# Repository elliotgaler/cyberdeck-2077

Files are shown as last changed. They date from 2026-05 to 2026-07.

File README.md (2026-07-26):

# CyberDeck-2077
A (WIP) CyberDeck project themed from the game CyberPunk 2077
CyberDeck -  a small, retro mini-pc running off basic hardware. They're a trend at the moment, which is where i got the idea to make one
The case, clips, hinges, attatchments etc. are all designed to be 3d printed, and attatched together with m2/m3 screws. I made this project because i have an interest in cybersecurity, and wanted to make a small, portable device that i could use to practice on. Even though it isn't hugely functional for that purpose right now (using only a relatively slow pi5), it is designed so that I have plenty of space to adapt it in the future if I want to. I love the game CyberPunk 2077, the associated tv show, and the cyberpunk style as a whole, and thought it an ideal aesthetic inspiration for the project.   
The cyberdeck features:
- Rasberry Pi 5 as the mainboard
- a 7 inch 1024x600 monitor
- a Rii x1 mini keyboard
- other components (rear ethernet port, usb-c port, cooling fan)

What i intend to use the deck for:
i'm super into cybersecurity rn and im hoping to go into work in that industry, so i'm going to insall some sort of linux distro (arch/kali) designed for cybersecurity and use it to practice skills related to cybersec. i also intend to do some other projects in fallout to compliment it. I might expand it in the future to include an internal battery, but i'm leaving it as a wall-power only for simplicity for now.

Future changes/plans:
- update USB ports on LowerCaseCover to fit the actual hub
- Add an internal battery
- integrate my other projetct (DiyRubberDucky), adding storage/attachment points
- 

FILES:  
construction files - the fusion CAD files, for the assembled and blown-up design + step files for ease of use
3mf files - the files ready for printing on a 3D printer  
documentation - word docu that i made to help me with the process + images of the process + bill of materials + fallout zine + wiring diagram

NOTE - as this is a WIP, files may not be fully functional as of 04/05/26 (dd/mm/yy) - hopefully once i physically build the cyberdeck, i can correct any small issues e.g. USB ports being misplaced due to a lack of dimensions on the product page for the USB hub

Copy of CyberDeck zine pdf







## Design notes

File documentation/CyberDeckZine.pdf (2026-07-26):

2077

## A Cyberpunk 2077-themed Cyberdeck/Mini PC

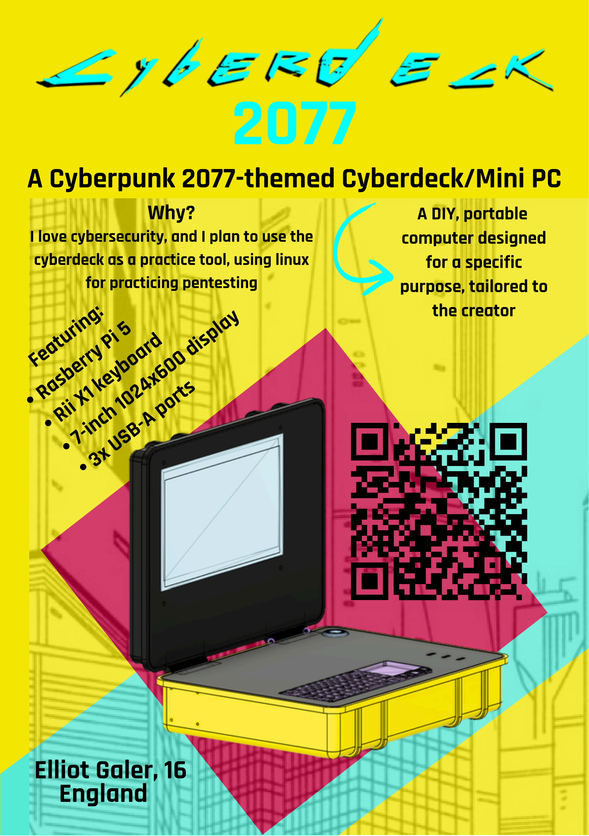
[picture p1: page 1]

## Elliot Galer, 16 England

### Featuring: Rasberry Pi 5 Rii X1 keyboard 7-inch 1024x600 display 3x USB-A ports

A DIY, portable
computer designed
for a specific
purpose, tailored to
the creator

### Why?

I love cybersecurity, and I plan to use the cyberdeck as a practice tool, using linux for practicing pentesting

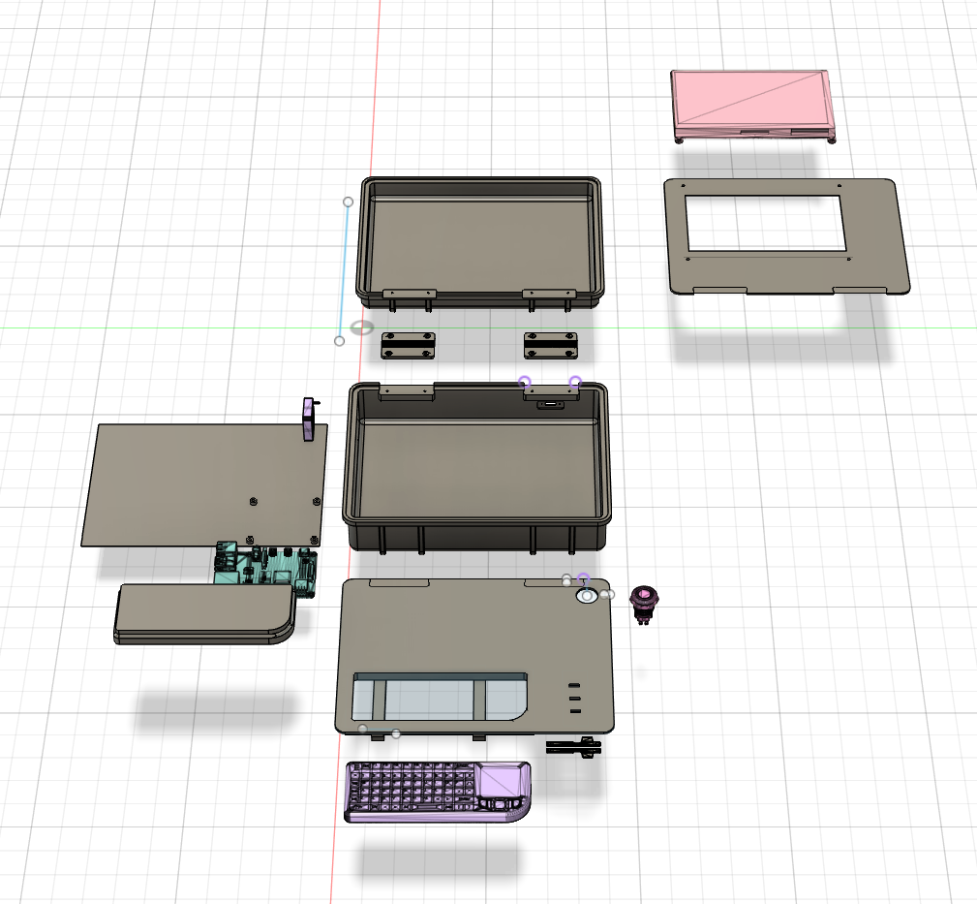
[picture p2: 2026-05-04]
documentation/images/Screenshot 2026-05-04 172059.png

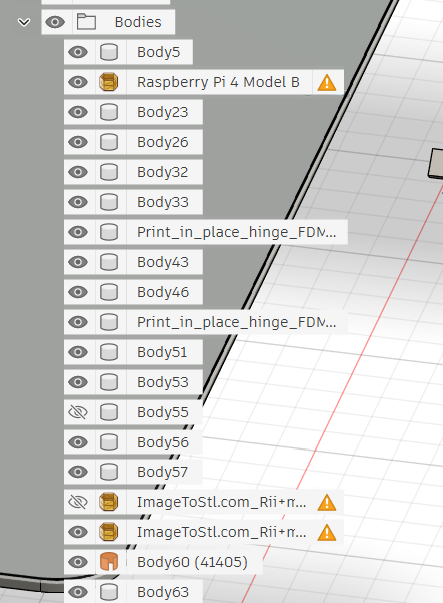
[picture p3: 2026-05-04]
documentation/images/Screenshot 2026-04-29 211012.png

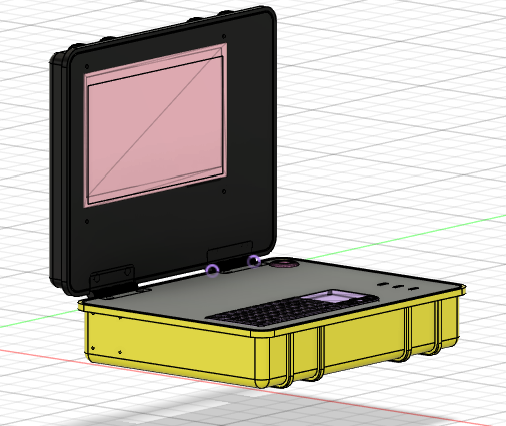
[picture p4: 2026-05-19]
documentation/images/Screenshot 2026-05-05 175419.png

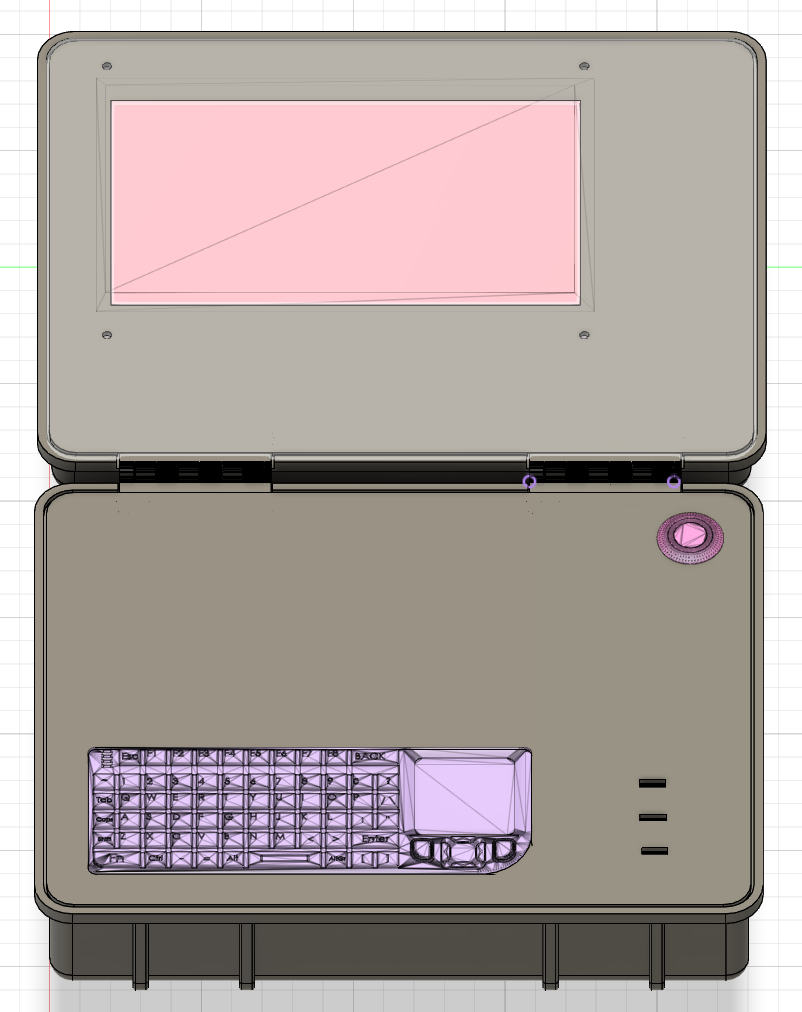
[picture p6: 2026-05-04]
documentation/images/Screenshot 2026-05-04 172925.png

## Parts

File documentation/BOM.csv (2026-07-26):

Bill of Materials
 | NAME | DESC | LINK | UNIT PRICE | UNIT AMOUNT | RUNNING TOTAL
 | Rasberry Pi 5 | The mainboard of the project | https://shorturl.at/4AiOK | £43.20 | 1 | £43.20
 | 7 Inch Screen | The screen for video output | https://shorturl.at/TB3XK | £20.19 | 1 | £63.39
 | Rii X1 keyboard | The keyboard/pointer for input | https://shorturl.at/DzRTy | £12.09 | 1 | £75.48
 | Rasberry Pi heatsink | Heatsink for the pi board | https://shorturl.at/3djcr | £1.89 | 1 | £77.37
 | Dupont cable | Cables for using pi pins | https://shorturl.at/Kwtkn | £1.28 | 1 | £78.65
 | Push button | Start button for pi board | https://rb.gy/n7qr61 | £2.06 | 1 | £80.71
 | Usb C splitter | Splitter to power board+screen | https://shorturl.at/PziXz | £2.38 | 1 | £83.09
 | USB hub | Hub to take ports to outside of case | https://shorturl.at/EItCf | £1.00 | 1 | £84.09
 | M2 screws | Screws for attaching parts | Purchase at hardware store (https://shorturl.at/QgxTS) | £0.10 | 25 | £86.59
 | M3 screws | Screws for attaching parts | Purchase at hardware store (https://shorturl.at/QgxTS) | £0.10 | 4 | £86.99
 | M2 inserts | For attaching screws to plastic | Purchase at hardware store (https://shorturl.at/QgxTS) | £0.10 | 25 | £89.49
 | M3 inserts | For attaching screws to plastic | Purchase at hardware store (https://shorturl.at/QgxTS) | £0.10 | 4 | £89.89
 | Ethernet extender | For external ethernet port | https://shorturl.at/F6xKs | £1.60 | 1 | £91.49
 | 3007 fan | 30mm fan for cooling pi | https://shorturl.at/X9jGS | £1.92 | 1 | £93.41
 | Wires | Wires for connecting components | Purchase at hardware store (https://shorturl.at/BUKeM) | £2.00 | 1 | £95.41
 | PETG fillament | High-strength fillament for printing case components | https://shorturl.at/1YEJ3 | £13.99 | 1 | £109.40
 | SD card extender | Cable for taking sd card from outside of case | https://shorturl.at/Pyktu | £1.99 | 1 | £111.39
 | USB-C extender | Cable for taking USB-C from the back of case | https://shorturl.at/ff3qk | £1.26 | 1 | £112.65
 | Micro-HDMI to HDMI | Cable for taking video from pi5 to display | https://shorturl.at/XtR4Q | £1.99 | 1 | £114.64
 | Keyboard power cable | Cable to power/charge keyboard | https://shorturl.at/65F7K | £2.12 | 1 | £116.76

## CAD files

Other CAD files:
Construction files/CyberDeckAssembled.step
3mf files/LowerHalf.3mf
3mf files/CableClip.3mf
Construction files/CyberDeckExpanded.step
3mf files/HingeUpper.3mf
3mf files/PiPlate.3mf
3mf files/UpperPlate.3mf
3mf files/UpperHalf.3mf
3mf files/UsbHubBar.3mf
3mf files/KeyboardBar.3mf
3mf files/LowerPlate.3mf
3mf files/HingeLower.3mf
Construction files/CyberDeckAssembled.f3d
Construction files/CyberDeckExpanded.f3d

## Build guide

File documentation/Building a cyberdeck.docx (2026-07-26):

Building a cyberdeck – documentation

Basic steps to building:

1. Research and idea building– researching what other people have done with their cyberdecks aesthetically – sizes, shapes, what containers to use/design etc. Then, research on electric components – what mainboard to use, keyboard, screen, battery/power connector etc. for the basics. Further components – USB hubs, Wi-Fi connectivity, buttons etc.
2. Initial CAD – designing the case, the slots for the components to sit – testing using placeholders etc.
3. Production and installation – Produce the final versions of the components, order the hardware, solder it all together and install into the case (maybe program first, depending on difficulty), finalise design.
4. Software – installing operating systems, connecting components together, downloading software etc.

STEP 1: RESEARCH:

Inspiration photos

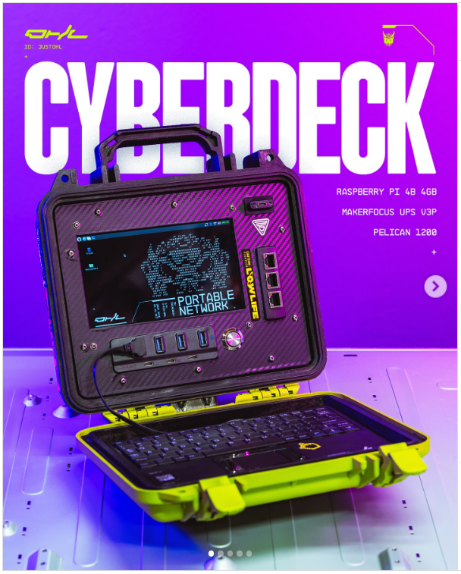
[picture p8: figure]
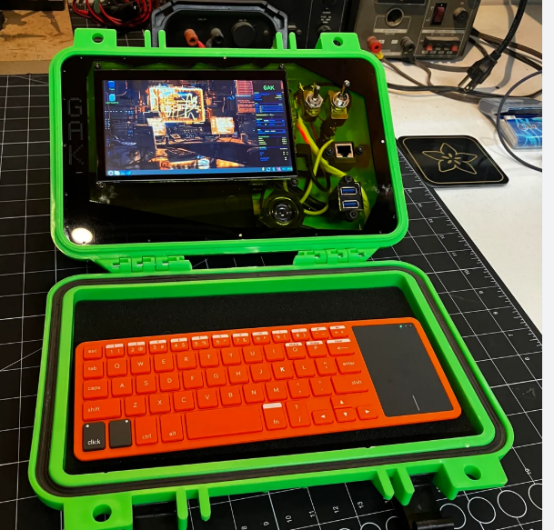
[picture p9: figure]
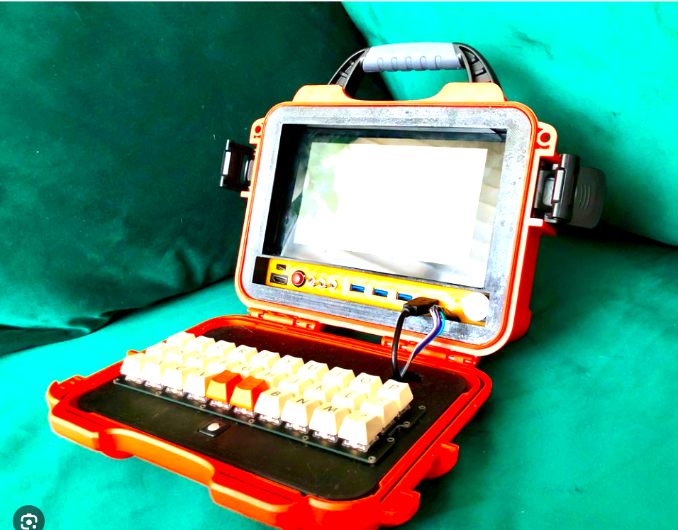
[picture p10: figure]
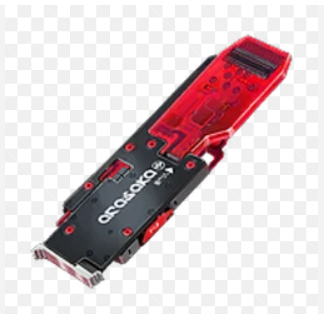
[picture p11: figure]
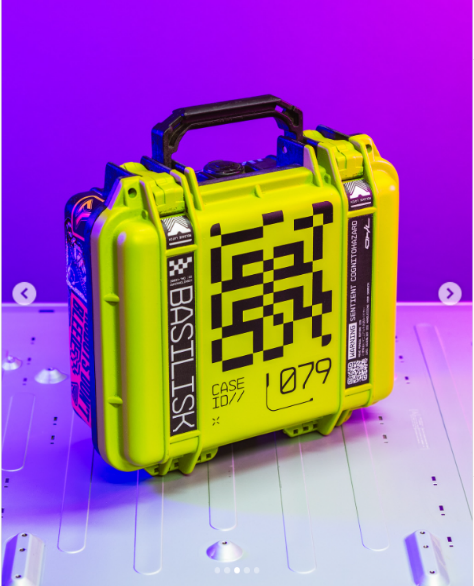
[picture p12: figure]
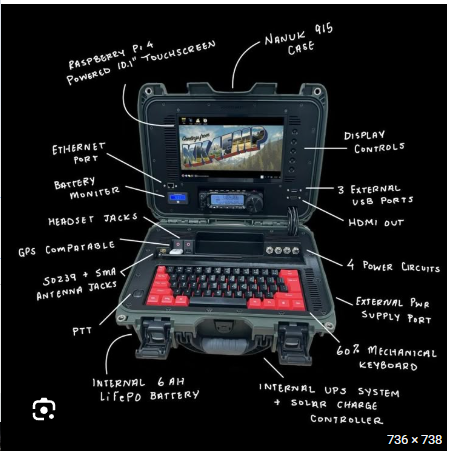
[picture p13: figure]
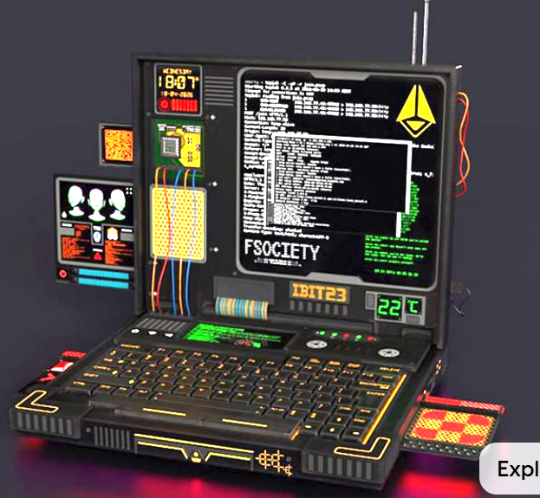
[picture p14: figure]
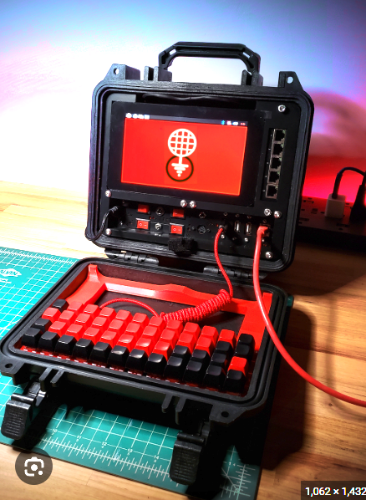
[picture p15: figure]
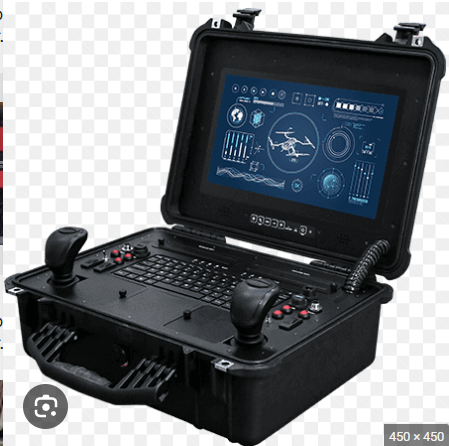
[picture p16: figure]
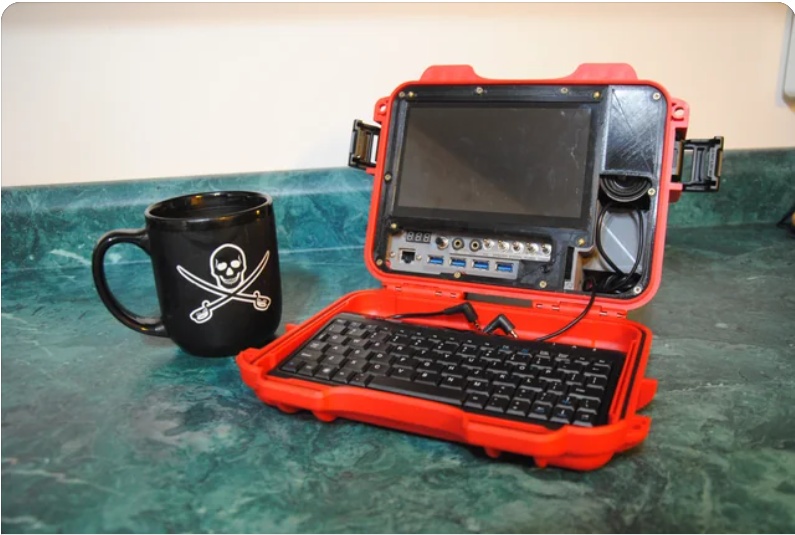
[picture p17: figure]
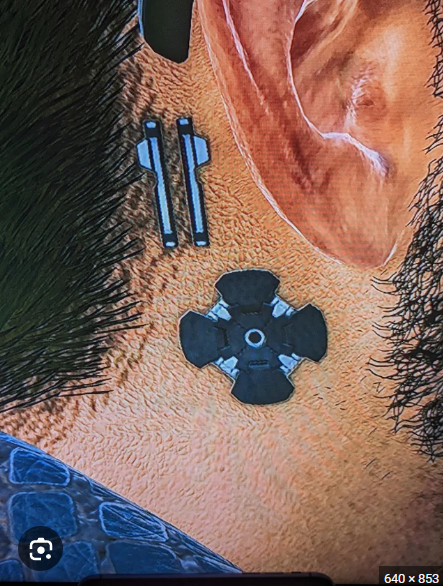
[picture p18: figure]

Idea building

Essentially – a cyberpunk themed cyberdeck. It should have basic computer functionality using some sort of small computer board – probably a raspberry Pi. It’ll have a keyboard and screen integrated, but a wireless mouse separately. I’d like it to have some sort of USB ports, probably using a usb hub that has the ports sat on the bottom half of the deck, and I’d quite like to have in in the style of a Neural port from cyberpunk (decorative only) as well as an audio port in the style of the personal link port (from the game). It should have WiFi connectivity, but that’s not an initial priority for it. Maybe I’ll also add an ethernet port, mostly for aesthetic purposes. It will need a power port of some sort somewhere, but I’m not sure if I want it to run off a battery or a wire. Maybe both, but I’m not sure how to do both now. A small screen for a battery monitor would be cool as well. It would also be cool to use the cyberdeck USB ports as an upgrade port as well, so that I could add more features in the future easily. For WiFi, it would need external antenna, so those would have to fit in somewhere. The whole cyberdeck should be able to fold shut, for transportation.

Electronics/components research

List of electronic components I might need:

1. Computer – the main computer for the cyberdeck. I’m going to use a raspberry pi, either the 3 or 4. The 4 seems better value – I think the 1gb ram is best, as the project is on a budget, and I can always upgrade the board later. Maybe use pi5 if budget allows. Approx. £33
2. Keyboard – a keyboard to integrate into the cyberdeck. Needs to be small, and able to fit nicely into the case. Also needs to be able to be strongly fixed in place somehow. Some sort of cheap amazon keyboard. Approx. £6
3. Main Screen – a screen to show the display of the computer. Ideally colour-enabled, but resolution and refresh rate can be low. Size needs to be 10-15cm wide and 7-12cm tall approx. https://shorturl.at/wK7ne from ali - good option. Approx. £36
4. Secondary screen – next to the main one
5. Battery/Power connector – for power for the components. Battery makes it portable, but power cable is probably cheaper/easier. Also battery requires charging board, and idk about those. I’m going to use a power cable -cheaper, easier. Can add battery later. Can use standard usb-c cable as power, so no charge there, but need usbc-f to usbc-m to take power from outside of case so approx. £3
6. Ethernet-to-ethernet cable – to extend the ethernet port from the pi board. I plan to initially use ethernet for internet connection as I think it’s easier (unless the computer has wifi built in) approx. £2
7. Audio jack extender – for the audio port on the deck. Approx £1
8. USB hub- for getting more USB ports. Approx. £3
9. Small fan for cooling computer board. Approx. £

List of electronic components I already have:

1. Wires – wires to connect the components (apart from the high-gauge wires for power)
2. Screws/bolts – for connecting things to the case
3. Hard drive for storage for the pc

List of non-electronic components I need:

1. 3D printing filament – something strong, and rigid, and that won’t decay over time. Ideally PETG or PCTG, as they are the strongest filaments I can safely print on my A1. PCTG is quite a bit more expensive, but also a bit stronger than PETG. I intend to use white filament so that anything I print can be easily painted over. Potentially, I’ll use white PCTG for only the outside case and then cheaper PETG for anything inside that is less structurally important. This would save costs. Already have PETG, assume ½ kilo of PCTG, so approx. £11
2. Metal rods – for the hinges of the case. use, approx. 4 Approx. £3
3. Heat-set inserts – for screwing things into the case (maybe not needed). approx. £2
4. Small heatsink for pi board. Approx. £4

Total approx. cost (very rough) = £101, $140

$140 dollars is 28hrs of work with grants from fallout, so some will probably be self-funded? Things to complete that are time-heavy is CAD, Installation, Software, and decoration etc.

STEP 2 – 3D modelling

CASE:

Case features:

Max 256mm square (3d print limits)

Ideally rectangular (1:1.3 size ratio)

Handle

Hinges

Should look like a carry case when closed

Dimensions:

I think about 23cm by 17.5cm is ideal, as it leaves plenty of space on the printer. Depth should be enough to store all components, but not too big. Start with 4cm deep

Internal dimensions (mm):

169.2 x 224.2 x 40 – main body

179 x 234 x 2 – lip at top

Useable base dimensions (need to print base parts separately as can’t print upside down):

160.3mm x 215.3mm

Will glue into case after printing

MODELLING SPACES FOR COMPONENTS

I need to model in spaces for components to fit – for parts I know what they will be, I’ll do it exactly, and for others, I’ll do it for a generic part that should be approx. the right size

Parts I know:

1. Raspberry Pi 4
2. 7 inch raspberry pi screen (need top half)

Generic parts:

1. Keyboard (temp)
2. Power cable connectors/ports (will vary largely in size, so may leave generic until purchases are made)
3. 30mm fan
4. USB hub

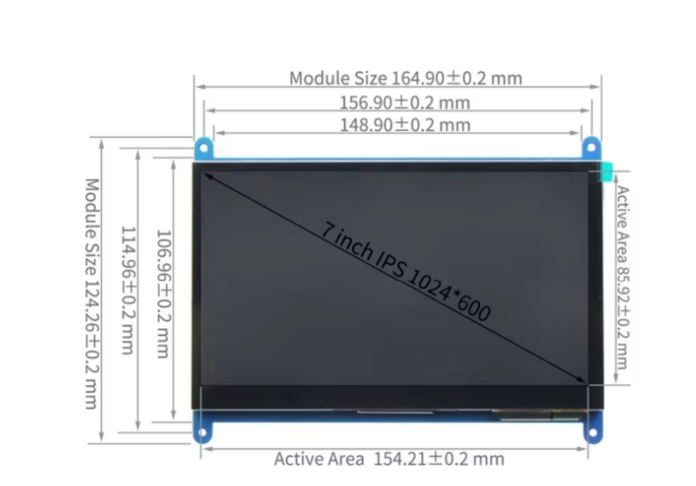
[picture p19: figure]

List of things that need changing after purchasing components:

- Screen hole
- Usb dock holesx

Fixing the files for final production

What needs fixing:

1. Add a hole for the ethernet cable connector on the back(DONE)
2. Move USB ports and make an accurate holder for the hub(DONE)
3. Make a way for cables to go from lower case to upper case (potentially combine with 1?) (DONE) (cables will be wrapped in electrical tape and a stopper will limit the angle of opening)
4. Build stopper for the cables to limit case angle (DONE)
5. Check fit for screen(DONE)
6. Check hole sizes for all screws+inserts

Test prints before final print:

1. Usb hub(DONE)
2. Keyboard(DONE)
3. Rear ethernet and usb-c holes (DONE-PERFECT)
4. Display(DONE)(maybye redo?)
5. Cable clips(DONE-PERFECT)

Screws/screw types needed:

8x m4 for hinges (+inserts)

16x m3 for case covers(+inserts)

8x m3 for usbhub and keyboard(+inserts)

4x (unknown, m2.5-3ish) for display

4x m2.5 for pi 5(screw straight into plastic?)

4x m2/2.5 for fan(need 4x small nut to hold it)

4x (same as display) for ethernet and usbc ports

Further features to decide on adding:

- Handle
- Locking clasps

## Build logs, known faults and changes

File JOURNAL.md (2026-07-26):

# CyberPunk Cyber-deck — Journal Export

- Exported at: 2026-07-26T12:44:38Z
- Project ID: 2610
- Entries: 27

## Entry 1
- ID: 3891
- Author: elliotgaler
- Created At: 2026-04-25T16:24:21Z

### Content

This is the journal for my project, a Cyberpunk 2077-themed cyberdeck

25/04/26
I started research today, starting with photo inspiration for the project and laying out steps that I need to take to complete the project.

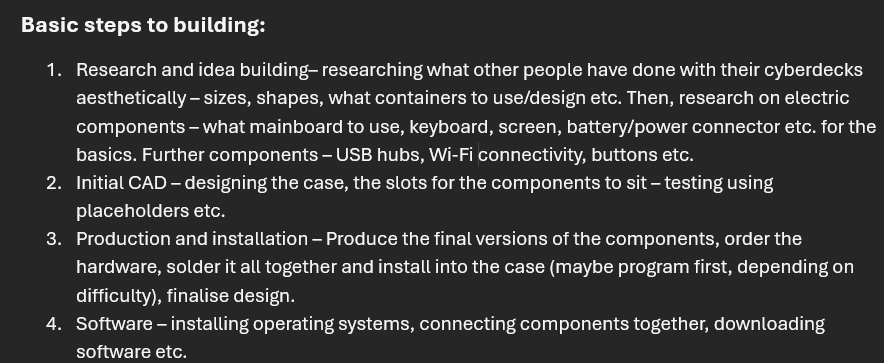
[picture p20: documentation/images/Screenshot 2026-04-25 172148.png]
Screenshot 2026-04-25 172148.png


I wrote out the basic idea of what I wanted from the finished product, and then compiled a list of the components that I would need for the project and their approximate prices, so that I could estimate the cost of the project.

### Recording Links

- https://lookout.hackclub.com/api/media/4405ce72-c4b7-4363-a341-66e24b83303a/video.mp4

## Entry 2
- ID: 4051
- Author: elliotgaler
- Created At: 2026-04-26T14:29:58Z

### Content

26/4/26
Started off with some updated research into mainboards and keyboards, and found better components than I had previously - I decided I didn't want to use a small keyboard like the KeebDeck that I had looked at before, so I decided to use a cheap 40%/mini Bluetooth keyboard

Moved into the beginnings of the CAD for the case of the cyberdeck, starting with the bottom of the case. Fairly simple to design, just took time to polish it off, and I'm sure it'll change again. At this point, it is just the bottom section of the case hollowed out, with decorative details on the outside but no hinges, clasps, or slots for hardware to be installed. 
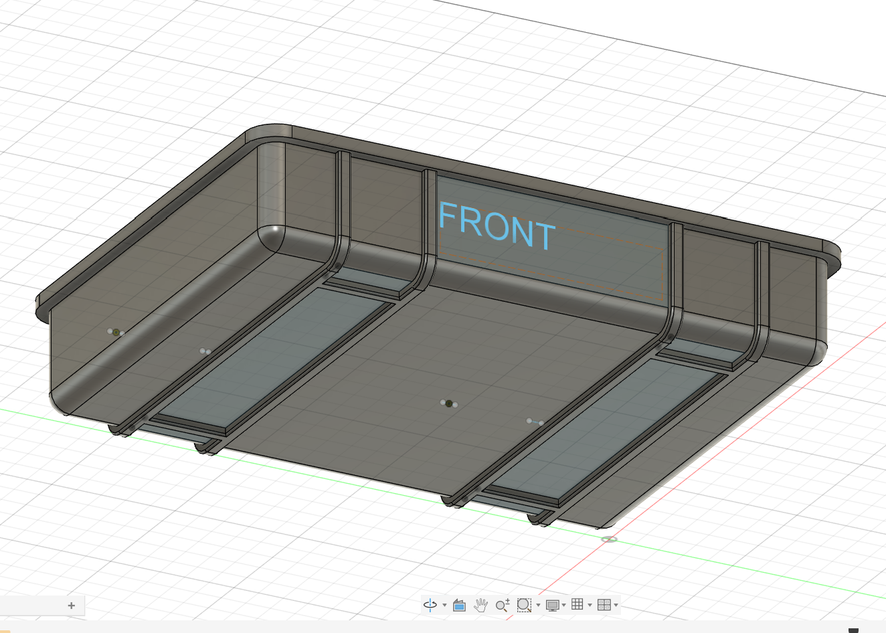
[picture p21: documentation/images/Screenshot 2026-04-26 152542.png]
Screenshot 2026-04-26 152542.png

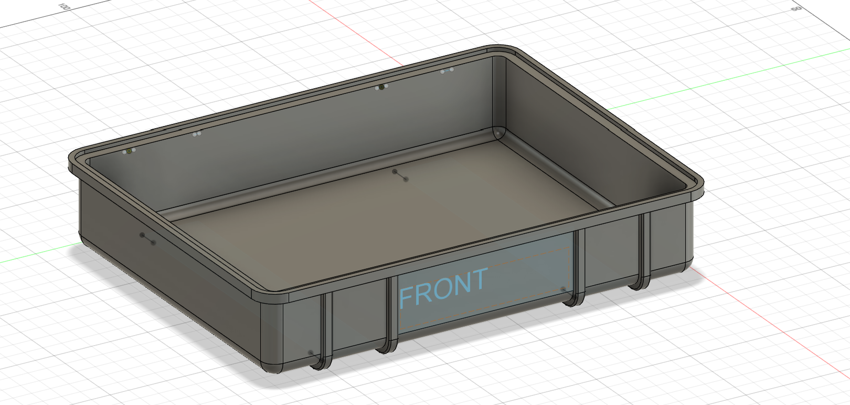
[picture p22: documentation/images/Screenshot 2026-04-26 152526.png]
Screenshot 2026-04-26 152526.png

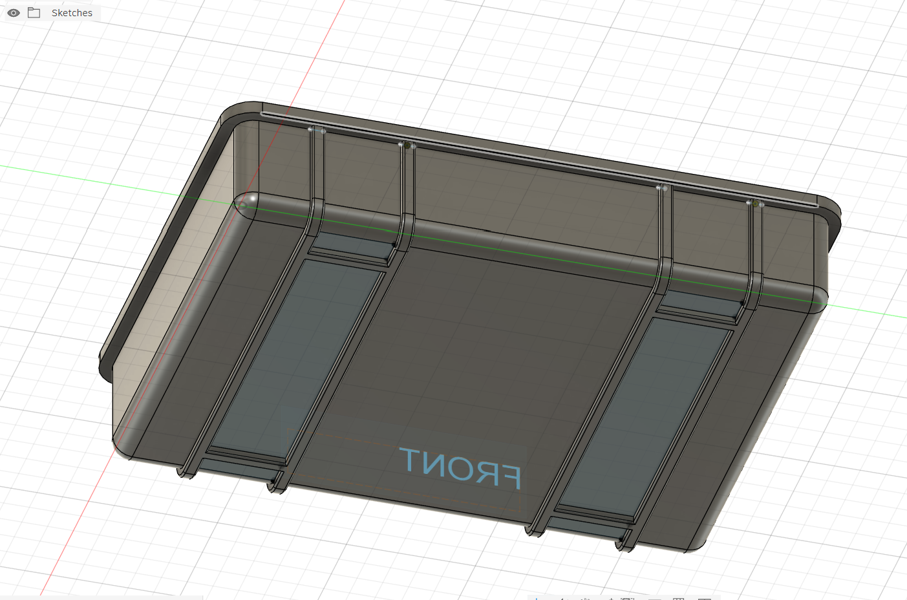
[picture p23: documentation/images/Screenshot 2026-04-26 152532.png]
Screenshot 2026-04-26 152532.png


### Recording Links

- https://lookout.hackclub.com/api/media/2600a046-b6fb-48de-bc44-524a75f680ac/video.mp4

## Entry 3
- ID: 4106
- Author: elliotgaler
- Created At: 2026-04-26T19:27:00Z

### Content

Did more CAD for the case, started building slots for specific electronics (Pi 4) and designing the top cover for the bottom part of the case
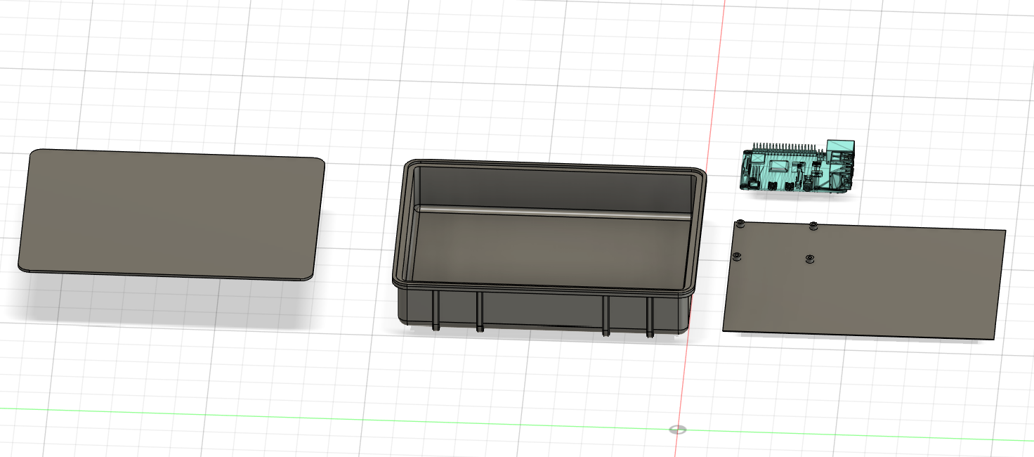
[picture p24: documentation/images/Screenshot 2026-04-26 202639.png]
Screenshot 2026-04-26 202639.png


### Recording Links

- https://lookout.hackclub.com/api/media/1ac716ec-1ffa-4c89-8069-7bb2de2314b7/video.mp4

## Entry 4
- ID: 4267
- Author: elliotgaler
- Created At: 2026-04-27T20:38:56Z

### Content

27/4/26
Further design on the bottom part of the case, and messing around with ideal screw sizes and the hinges. Did a test print for some Print-in-place hinges which went well :). Lots of errors made, screw sizes are really confusing. 
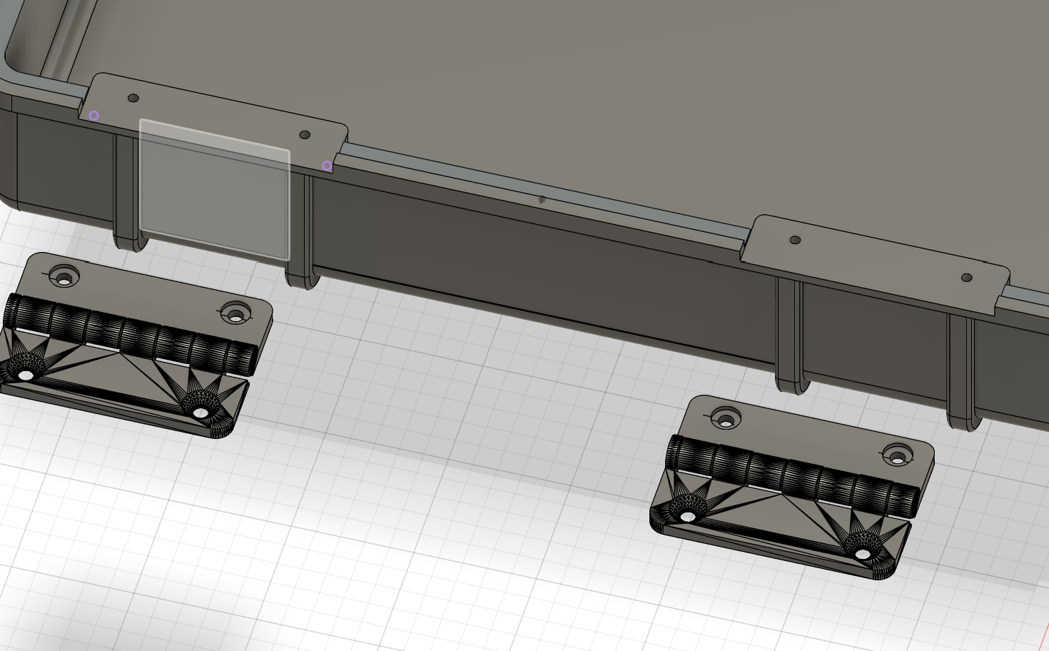
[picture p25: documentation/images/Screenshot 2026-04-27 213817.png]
Screenshot 2026-04-27 213817.png



### Recording Links

- https://lookout.hackclub.com/api/media/1ab56955-1144-40eb-9cbb-87490f9fc08d/video.mp4

## Entry 5
- ID: 4382
- Author: elliotgaler
- Created At: 2026-04-28T18:29:13Z

### Content

28/4/26
short cad session starting the design of the top cover for the bottom case, and rounding corners
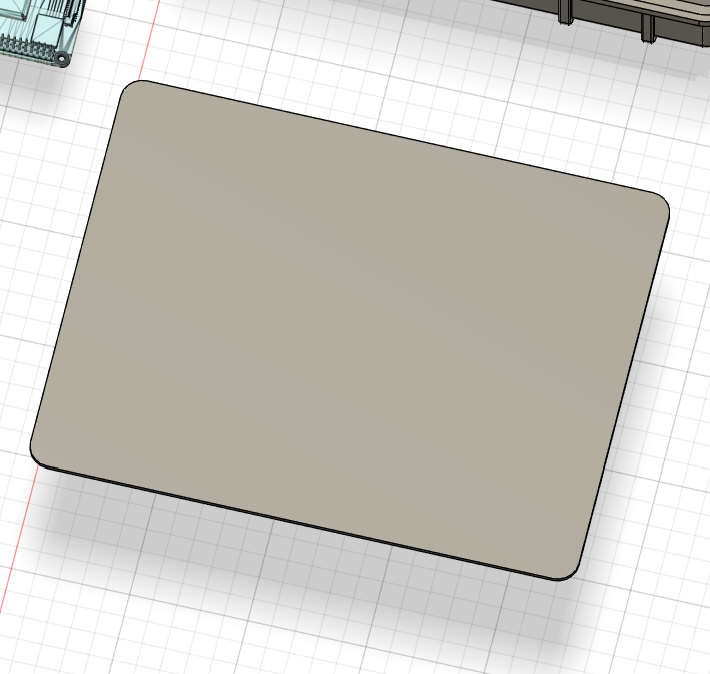
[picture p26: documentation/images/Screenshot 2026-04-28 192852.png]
Screenshot 2026-04-28 192852.png


### Recording Links

- https://lookout.hackclub.com/api/media/fa9d5c09-42ec-4346-9267-840f83a7d7f0/video.mp4

## Entry 6
- ID: 4404
- Author: elliotgaler
- Created At: 2026-04-28T21:13:43Z

### Content

more work on the top cover of the bottom part of the case, and struggling to import a mesh (damm stl files).
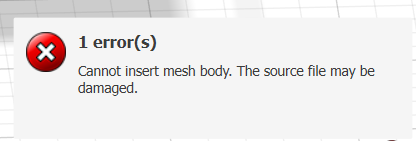
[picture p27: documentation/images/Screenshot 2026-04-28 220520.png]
Screenshot 2026-04-28 220520.png


### Recording Links

- https://lookout.hackclub.com/api/media/162b790a-8967-47d8-9a10-9dfb21c4fbe0/video.mp4

## Entry 7
- ID: 4537
- Author: elliotgaler
- Created At: 2026-04-29T20:39:21Z

### Content

Trying to use a model of my chosen keyboard component to model a spot for it in the case but obviously fusion doesn't like me so had to start modelling the component entirely by hand
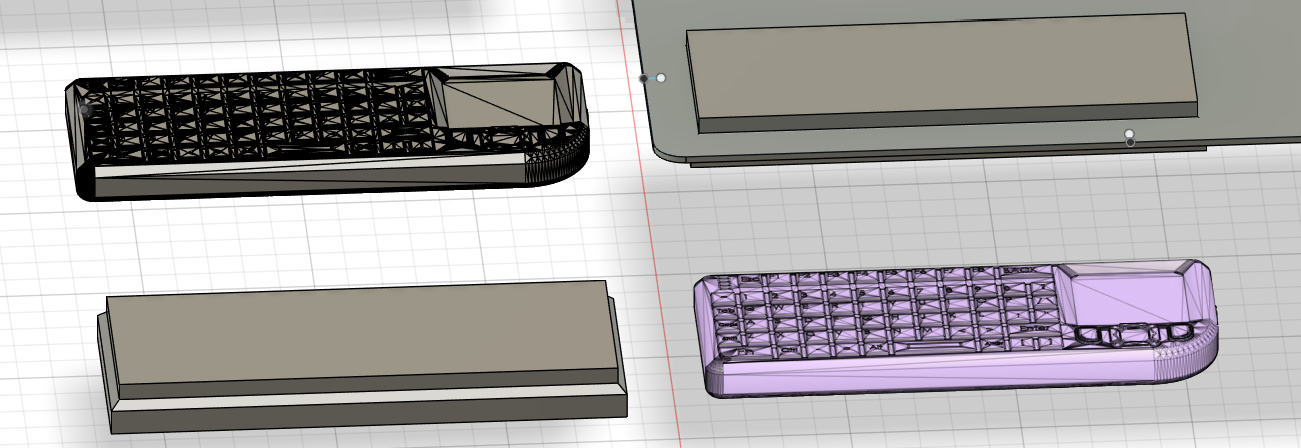
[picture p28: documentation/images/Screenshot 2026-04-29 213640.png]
Screenshot 2026-04-29 213640.png


### Recording Links

- https://lookout.hackclub.com/api/media/3b6cbe93-75dd-45b8-ae53-1bca4c2292b3/video.mp4

## Entry 8
- ID: 4669
- Author: elliotgaler
- Created At: 2026-04-30T20:41:50Z

### Content

More CAD for the keyboard component, went mostly well and defo getting closer to finishing the lower half of the case :)
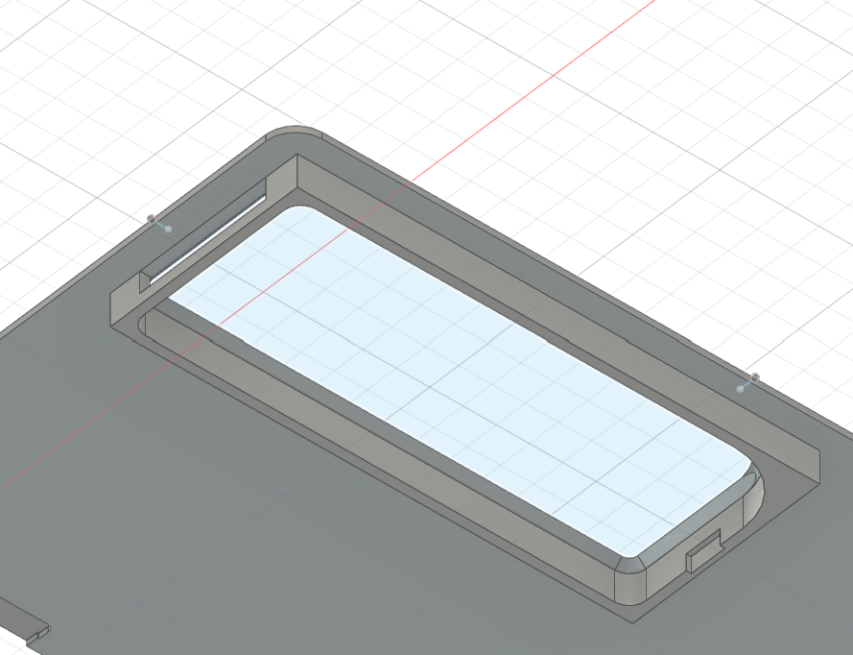
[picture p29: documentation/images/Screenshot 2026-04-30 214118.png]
Screenshot 2026-04-30 214118.png

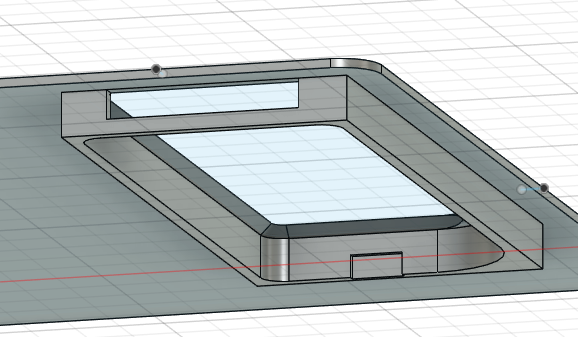
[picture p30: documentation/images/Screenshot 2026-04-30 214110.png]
Screenshot 2026-04-30 214110.png


### Recording Links

- https://lookout.hackclub.com/api/media/5db4787d-8cb6-46ae-9753-4c0dfce4b329/video.mp4

## Entry 9
- ID: 5323
- Author: elliotgaler
- Created At: 2026-05-03T19:05:42Z

### Content

More cad for the bottom case cover, inserting fasteners for the keyboard and holes for the usb ports and power button (both temp as don't know actual dimensions of components), and designed cover for top half of case including mounting points for the screen. Also more component research (power buttons, usb-c splitters etc)
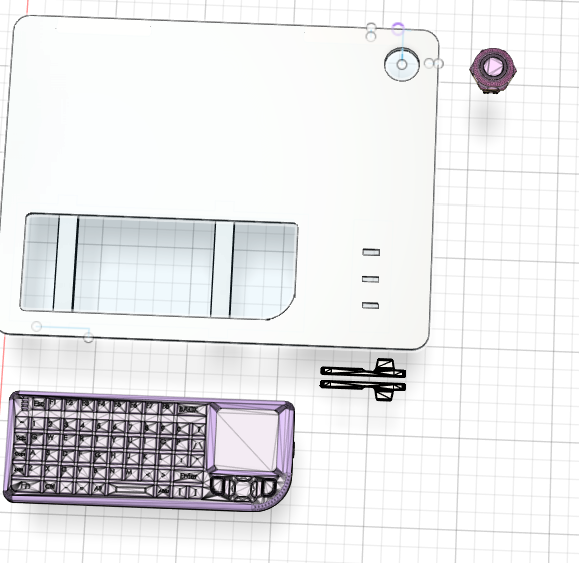
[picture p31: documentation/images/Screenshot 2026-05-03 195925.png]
Screenshot 2026-05-03 195925.png

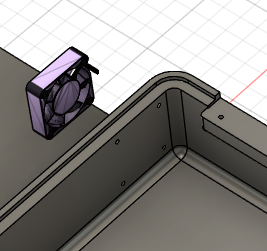
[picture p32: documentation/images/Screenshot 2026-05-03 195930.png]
Screenshot 2026-05-03 195930.png

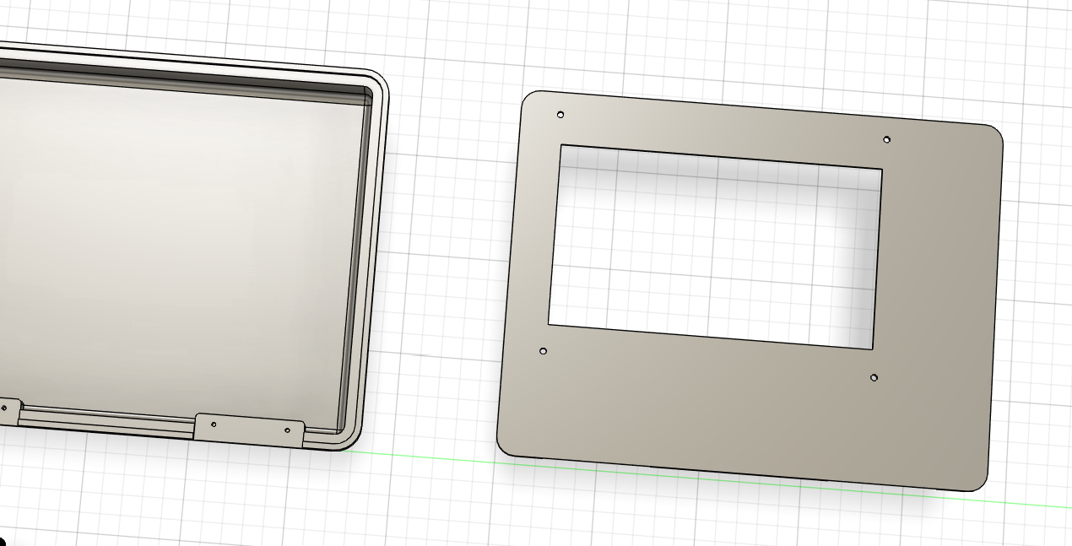
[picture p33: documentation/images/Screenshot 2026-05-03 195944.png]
Screenshot 2026-05-03 195944.png


### Recording Links

- https://lookout.hackclub.com/api/media/3b5babe1-515a-49d1-b15e-4fce6d7c00f8/video.mp4

## Entry 10
- ID: 5486
- Author: elliotgaler
- Created At: 2026-05-04T20:37:43Z

### Content

Finished up CAD on the case, then did lots of file management - 3mf files for each part into the github, f3d files for the expanded and assembled model, wrote the readme, learned partially how to use git (never again), wrote BOM, and prepared everything for submitting design.
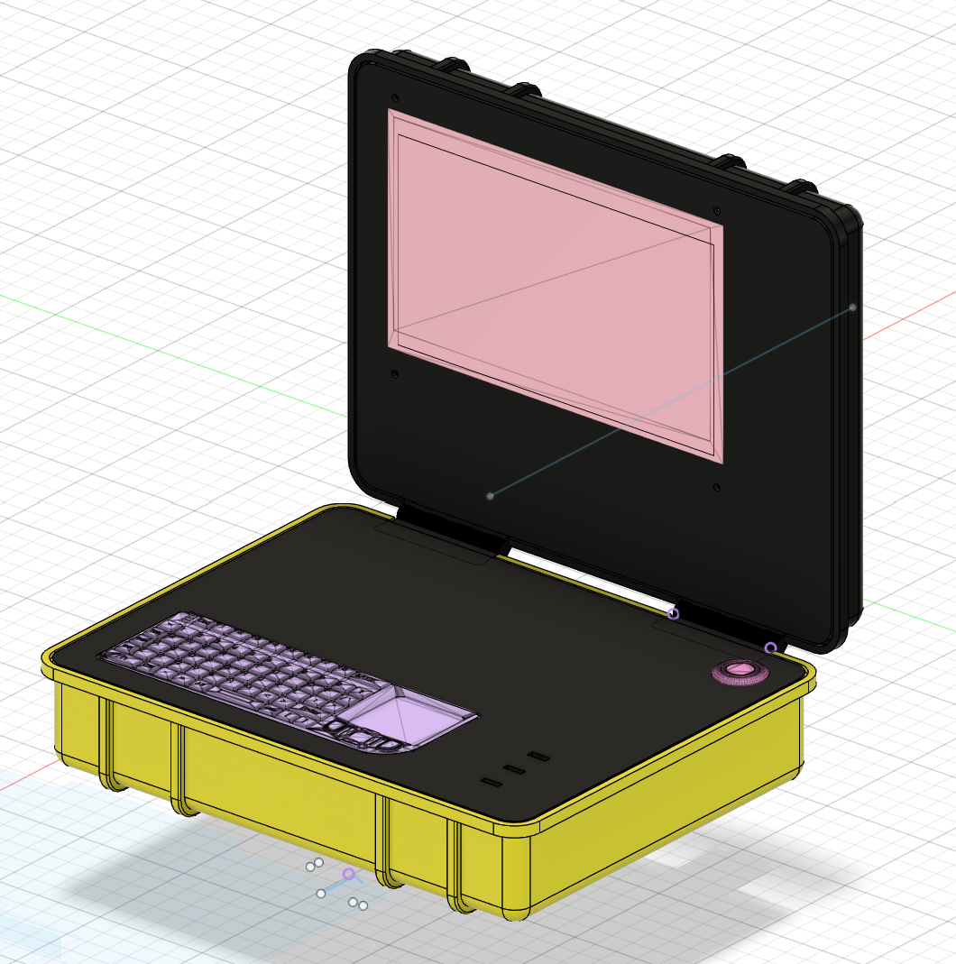
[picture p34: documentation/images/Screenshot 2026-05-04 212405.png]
Screenshot 2026-05-04 212405.png

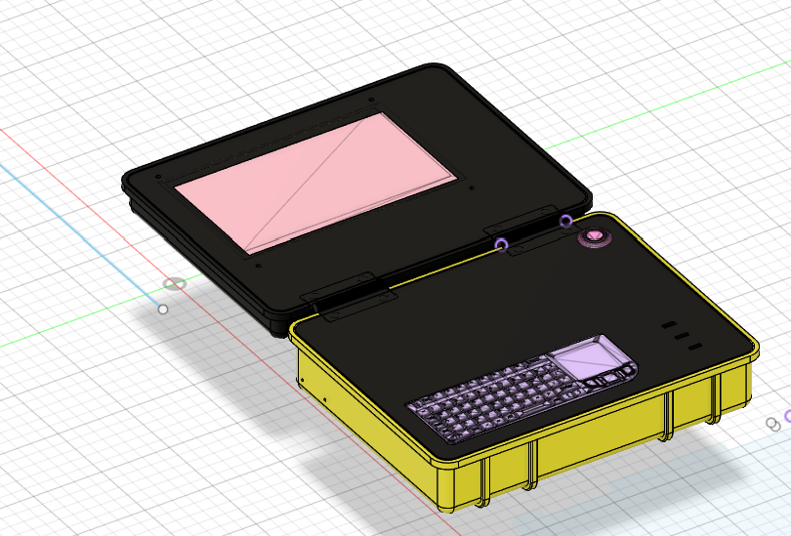
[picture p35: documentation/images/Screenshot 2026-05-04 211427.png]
Screenshot 2026-05-04 211427.png


### Recording Links

- https://lookout.hackclub.com/api/media/a8936ad9-65ed-4bff-a324-4b9cc644090a/video.mp4

## Entry 11
- ID: 5625
- Author: elliotgaler
- Created At: 2026-05-05T20:17:39Z

### Content

Made first design for the zine poster, with research for inspiration and then collating ideas into the document, finalising my v1 design

Cyber Punk V1.jpg

### Recording Links

- https://lookout.hackclub.com/api/media/e9d41b7b-2b14-49e0-8ae7-654521495293/video.mp4

## Entry 12
- ID: 5636
- Author: elliotgaler
- Created At: 2026-05-05T21:02:54Z

### Content

did more work on the poster, experimenting with colours and moving things around, and settled on a final design to  (i think) finish up the design ready for submitting!



### Recording Links

- https://lookout.hackclub.com/api/media/9188dec0-2f07-4fa8-a84b-99a6eb1bea8b/video.mp4

## Entry 13
- ID: 5796
- Author: elliotgaler
- Created At: 2026-05-06T20:50:12Z

### Content

Realised i hadn't added attachment points to the case cover, so started working on points for heat inserts on the lower case cover. also moved keyboard hole away from edge of case
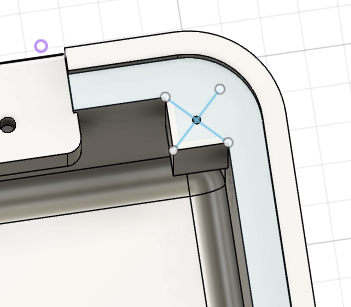
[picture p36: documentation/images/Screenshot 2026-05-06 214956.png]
Screenshot 2026-05-06 214956.png


### Recording Links

- https://lookout.hackclub.com/api/media/001bf643-95fe-4c78-a547-ce42329ef3ce/video.mp4

## Entry 14
- ID: 5874
- Author: elliotgaler
- Created At: 2026-05-07T10:28:53Z

### Content

more cad on the fixing points for the case covers and making holes on the covers to mark where the screws should go + fixing other small errors
Screenshot 2026-05-07 112822.png
Screenshot 2026-05-07 112812.png

### Recording Links

- https://lookout.hackclub.com/api/media/fe32c67c-b2b1-4f5f-8502-de153798e182/video.mp4

## Entry 15
- ID: 5895
- Author: elliotgaler
- Created At: 2026-05-07T13:34:50Z

### Content

fixing issues with some placements and preparing files again to upload to the github repo with the updates
Screenshot 2026-05-07 143105.png

### Recording Links

- https://lookout.hackclub.com/api/media/a3624aa0-8dda-429f-986f-a866e18c0d97/video.mp4

## Entry 16
- ID: 6637
- Author: elliotgaler
- Created At: 2026-05-11T18:36:21Z

### Content

creating a wiring diagram for resubmission, couldn't find a pi 5 schematic so i had to create one out of shapes :)


### Recording Links

- https://lookout.hackclub.com/api/media/e0c8c05c-dd23-41d1-9322-9c71564a40c7/video.mp4

## Entry 17
- ID: 6646
- Author: elliotgaler
- Created At: 2026-05-11T19:14:52Z

### Content

finishing wiring diagram for the deck so i can resubmit the project yaay, used rectangles for the different components and everything's labeled so should be easy to read


### Recording Links

- https://lookout.hackclub.com/api/media/aa42bf57-8e0a-42c0-9d48-adf7b4b0cf4e/video.mp4

## Entry 18
- ID: 7482
- Author: elliotgaler
- Created At: 2026-05-16T19:36:29Z

### Content

Built a model of the BadUSB that will go with the cyberdeck, using a arduino beetle board and a microsd port. imported a model of The Relic from Cyberpunk2077, and then cut holes to store the board and the port. started making a storage hole in the lower area of the cyberdeck.


### Recording Links

- https://lookout.hackclub.com/api/media/80a10b12-7f31-4d45-9f59-a3b64bec3ed3/video.mp4

## Entry 19
- ID: 8040
- Author: elliotgaler
- Created At: 2026-05-19T21:14:10Z

### Content

fixing issues for resubmission, such as fixing the assembly diagram, adding more to the zine and readme, and updating files/adding images of wiring diagrams as well as .epro files
Copy of CyberDeck zine.pdf.png

### Recording Links

- https://lookout.hackclub.com/api/media/8dea9969-48ee-4478-a9c4-55bc142ce514/video.mp4

## Entry 20
- ID: 8112
- Author: elliotgaler
- Created At: 2026-05-20T09:00:41Z

### Content

fixing the BOM by adding some wires that i missed, and moving around files in the github repo so that they're up to date and easier to find


### Recording Links

- https://lookout.hackclub.com/api/media/a2b89a75-c2b5-438c-a3b4-0f5f19bc58b5/video.mp4

## Entry 21
- ID: 14089
- Author: elliotgaler
- Created At: 2026-06-14T20:39:18Z

### Content

Added text to word  file on what needs changing before final print, and added holes on bottom/top of case to carry wires through and also the start of a place to install the usb-c cable that goes in the back of the case


### Recording Links

- https://lookout.hackclub.com/api/media/1ee99828-ad1e-4a91-8bc2-4b05adcd22c1/video.mp4

## Entry 22
- ID: 14315
- Author: elliotgaler
- Created At: 2026-06-15T20:42:33Z

### Content

designed spaces for the back usb-c port and jr45 jack to screw into, and also designed a model of the usb-hub to make the correct holes on the lower case



### Recording Links

- https://lookout.hackclub.com/api/media/285448aa-98ec-43fd-8e7c-9cd83d9478dc/video.mp4

## Entry 23
- ID: 16116
- Author: elliotgaler
- Created At: 2026-06-23T21:21:56Z

### Content

did some final touches on the cad, such as adjustments for the fits for the parts that i now have, like fixing the display mount, and adding a box to hold the usb hub. pretty close to finishing the design :)
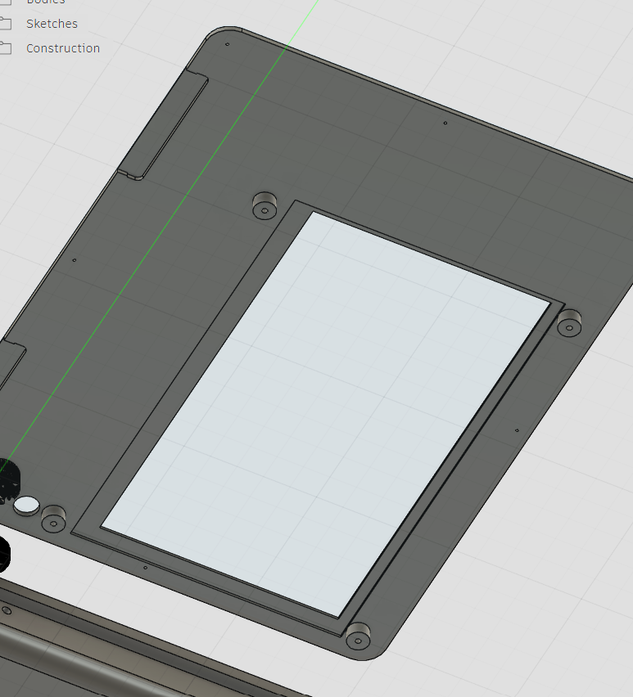
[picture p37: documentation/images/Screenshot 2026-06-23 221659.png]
Screenshot 2026-06-23 221659.png

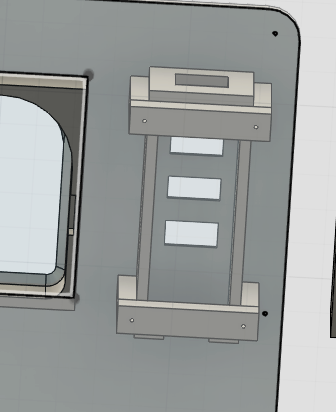
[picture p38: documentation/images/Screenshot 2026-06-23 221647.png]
Screenshot 2026-06-23 221647.png


### Recording Links

- https://lookout.hackclub.com/api/media/268a10a0-2fee-4449-8e1d-e78f3d9074cf/video.mp4

## Entry 24
- ID: 16150
- Author: elliotgaler
- Created At: 2026-06-24T14:22:02Z

### Content

Cut out certain parts of the build to print in PLA and test fittings and sizes, such as the ethernet/usbc slots at the back and the clip that will be used to grip the cable going from the bottom of the case to the top. (points where the recording paused was when i was taking measurements from components/of test prints


### Recording Links

- https://lookout.hackclub.com/api/media/73589da5-d1a4-45e9-bb0a-77a16804d627/video.mp4

## Entry 25
- ID: 16173
- Author: elliotgaler
- Created At: 2026-06-24T21:11:11Z

### Content

Printed test models of key parts of the case, like the keyboard mount, usbhub mount, and the display mount, and made adjustments to the model based on this.
Image (2).jpg

### Recording Links

- https://lookout.hackclub.com/api/media/28e3a1a1-2cc2-4c7f-89f8-d365d531fbad/video.mp4
- https://lookout.hackclub.com/api/media/da30b861-4d1a-432d-a982-a8d7eef728e9/video.mp4
- https://lookout.hackclub.com/api/media/94391f39-9273-4f16-b3a8-eaa6dd1abc9d/video.mp4

## Entry 26
- ID: 16390
- Author: elliotgaler
- Created At: 2026-06-29T20:29:34Z

### Content

Started designing a carry handle for the case, to have clips for fixing the case shut attached to it later
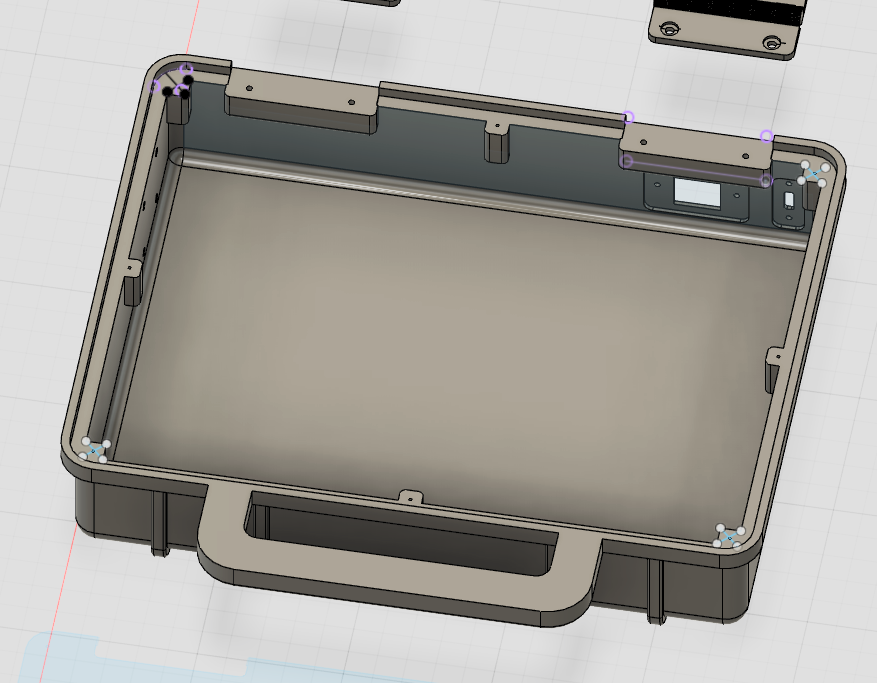
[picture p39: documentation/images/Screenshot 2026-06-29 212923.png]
Screenshot 2026-06-29 212923.png


### Recording Links

- https://lookout.hackclub.com/api/media/b373e69e-2966-4e8f-837e-157c0588c929/video.mp4

## Entry 27
- ID: 16786
- Author: elliotgaler
- Created At: 2026-07-22T22:13:35Z

### Content

display test 2 - reprinted display mount and tested it again to make sure the display would fit (it did)
Fitting holes for screws - ordered bolts+inserts from ali so making sure all the holes are the right size, but having to do each one manually so it takes forever :(



### Recording Links

- https://lookout.hackclub.com/api/media/b398b3a4-8498-4f79-b429-abff4e84d0b8/video.mp4
- https://lookout.hackclub.com/api/media/5c0955a3-5948-4c3f-be8e-29bf78cce831/video.mp4

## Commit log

2026-05-04 adding files with git lfs
    [CyberDeckAssembled.f3d, CyberDeckexpanded.f3d]
2026-05-04 add 3mf files with git lfs
    [ElectronicsPlate.3mf, KeyboardFastener.3mf, LowerCase.3mf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]
2026-05-04 adding step files
    [CyberDeckAssembled.step, CyberDeckExpanded.step]
2026-05-11 update files
    [BOM.csv, CyberDeckAssembled.f3d, CyberDeckAssembled.step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]
2026-07-26 Add OneDrive folder
    [BOM.csv, CableClip.3mf, CyberDeckAssembled.f3d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]
